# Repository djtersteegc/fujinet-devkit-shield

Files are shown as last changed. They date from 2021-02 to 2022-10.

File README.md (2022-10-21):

# fujinet-devkit-shield

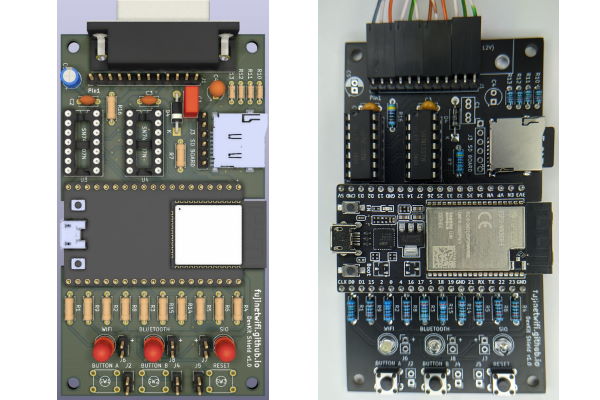
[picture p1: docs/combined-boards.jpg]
combined-boards


This is an alternative hardware platform for [FujiNet](https://fujinet.online/) that allows you to build your own using all through-hole technology (THT) components and an Espressif ESP32-DevKitC-VE devkit board.  You could probably also use a ESP32-DevKitC-VIE board, but you will need to either use an external IPEX connected antenna or engage in some micro soldering since the on-board PCB antenna is not connected by default. You must use ESP32-WROVER based devkit boards, the cheaper ESP32-WROOM boards lack the PSRAM needed by FujiNet code these days. 

The PCB is designed for flexibility in building, with different cabling options and headers for the buttons and LEDs if you want to mount this in your own enclosure. Most components are "jelly bean" parts you may already have or can be purchased for one or two cents in quantity from the usual China based suppliers.  Total cost of the build should be around $20, depending on where you source your parts.  Please see the assembly page for more details.

[Hardware Component Choices and Assembly](https://djtersteegc.github.io/fujinet-devkit-shield/assembly.html)

An interactive BOM and parts placement diagram is also available.

[Interactive Bill of Materials (BOM)](https://djtersteegc.github.io/fujinet-devkit-shield/ibom.html)

Currently this board is not supported by the FujiNet updater app so you will need to use Platform IO to build and upload your own binaries.  Build with the 8MB flash target since the devkit boards have half the flash of the 16MB WROVER modules used on the SIO mounted FujiNet designed by [mozzwald](https://github.com/mozzwald).  In normal operation is should not really matter since 6MB in the 16MB version is currently reserved for over the air (OTA) updates and the release build uses a little more than 2MB of flash as of March 2021 so lots of free space still for future development.

[Board bring up for FujiNet Platform.IO code](https://github.com/FujiNetWIFI/fujinet-platformio/wiki/Board-bring-up-for-FujiNet-Platform.IO-code)

STL's and the [DesignSpark Mechanical](https://www.rs-online.com/designspark/mechanical-software) source file for a 3D printable enclosure are in the **enclosure** directory. Assemble with four M3x10mm screws. Make sure to print 3 copies of the button file.

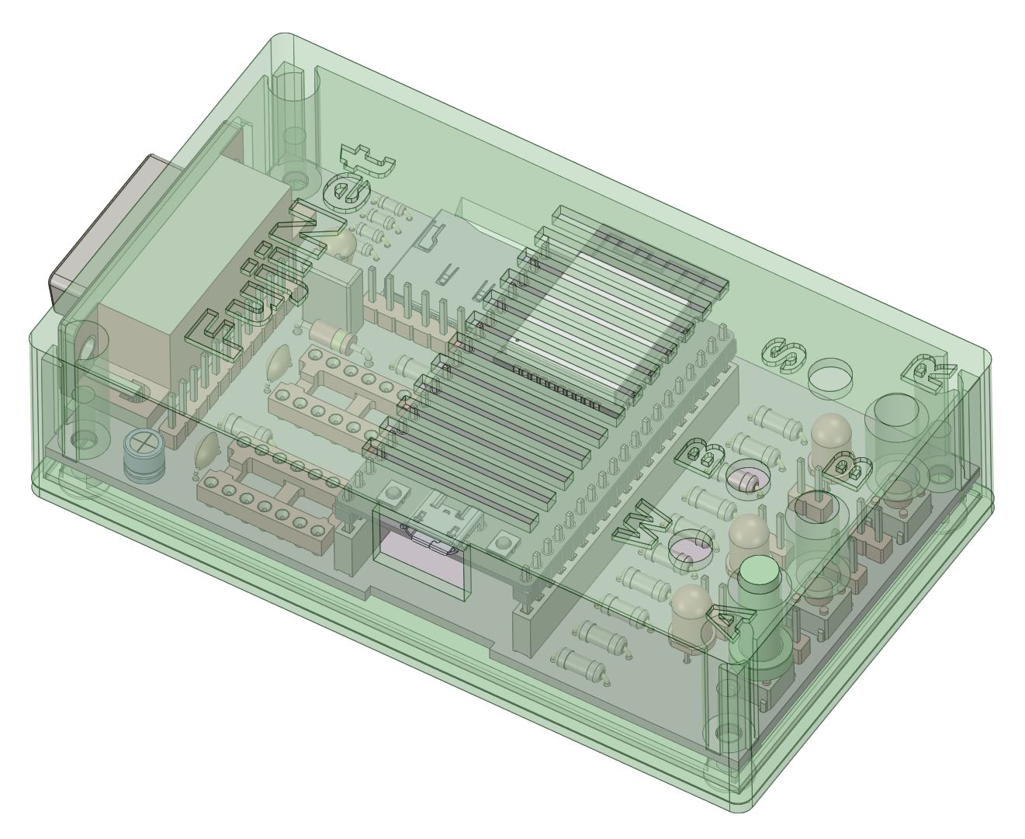
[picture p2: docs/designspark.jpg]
designspark


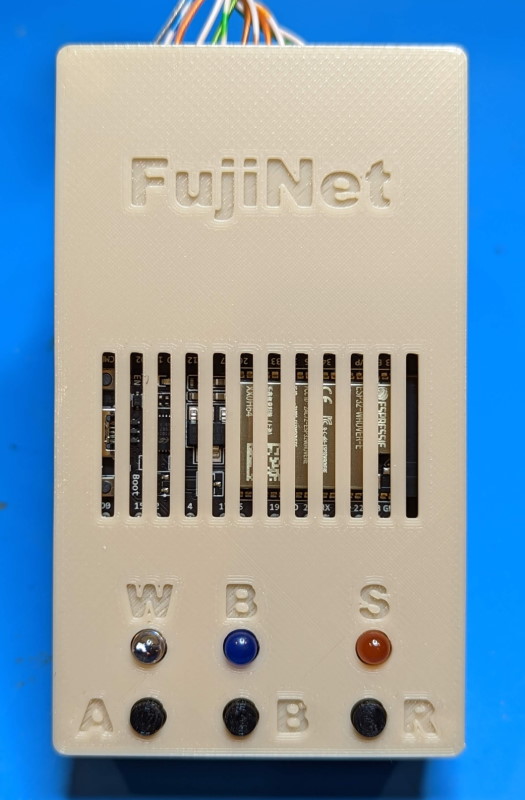
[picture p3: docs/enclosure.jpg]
enclosure


# Getting a Board

If I have extra PCB's, they will be listed on Tindie.

[https://www.tindie.com/products/tersteeg/fujinet-devkit-shield/](https://www.tindie.com/products/tersteeg/fujinet-devkit-shield/)

Otherwise you can download the Gerbers and use your favorite fab (JLCPCB, PCBWay, etc.) to make your own batch.  It's a standard two layer, 1oz copper board with dimensions of 99mm x 56mm so it squeaks under the 100mm x 100mm limit of the cheap Chinese fabs.

# Hardware Revisions

### Version 1.0

Mostly tested. Standard pin header cable with the SMD MicroSD card connector works.  Still waiting for DB15 connectors to test that cable configuration and a 4.7uf ceramic cap for audio in line. Will also build that one with the micro SD breakout board to verify.  External pin headers for the buttons and LEDs are also untested, but should work. Equivalent to version 1.3+ (pull-up resistors on the SIO and SD card lines) of the SIO port mounted FujiNet.

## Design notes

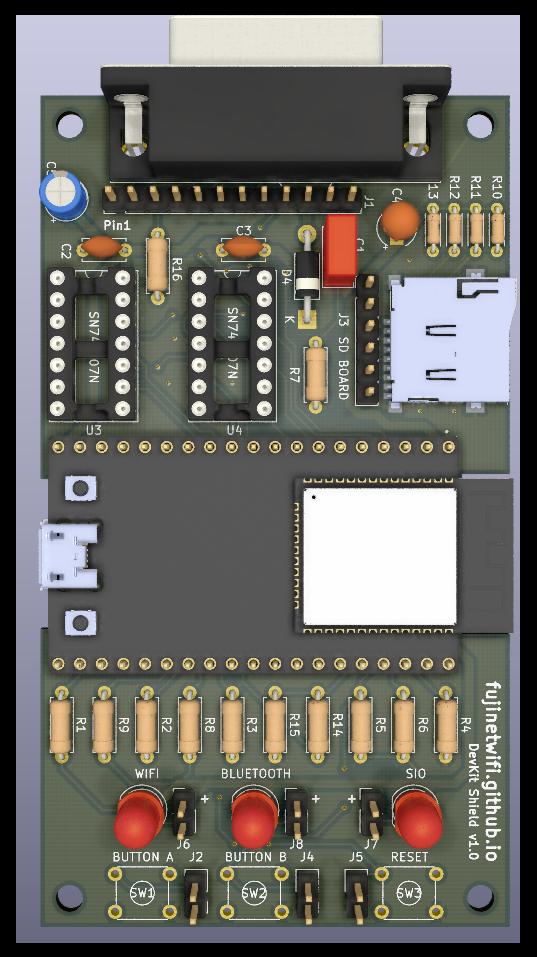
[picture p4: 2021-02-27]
docs/kicad-render.jpg

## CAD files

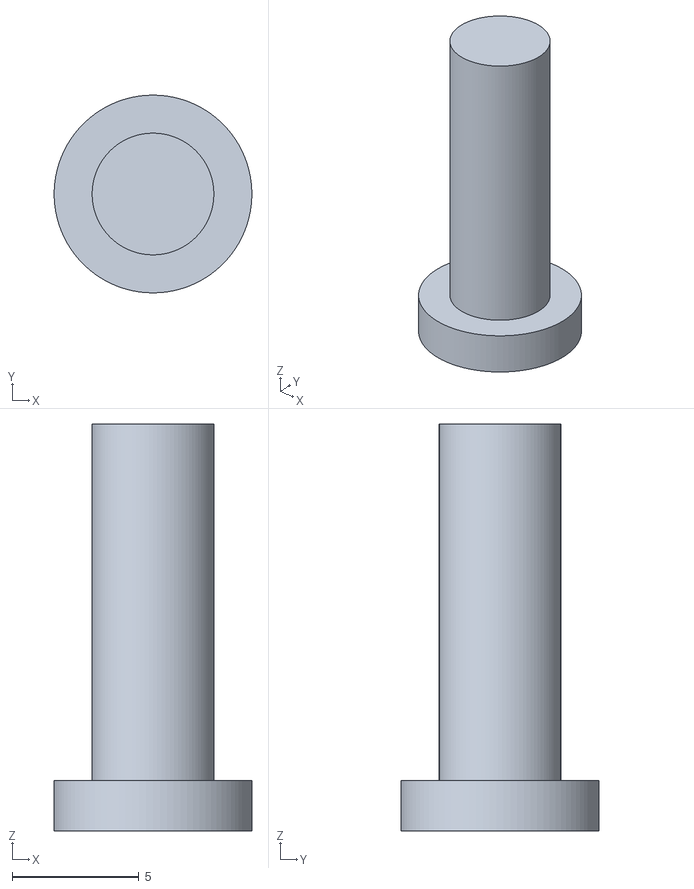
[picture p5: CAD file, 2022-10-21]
enclosure/fujinet button.stl
7.80 x 7.80 x 16.0

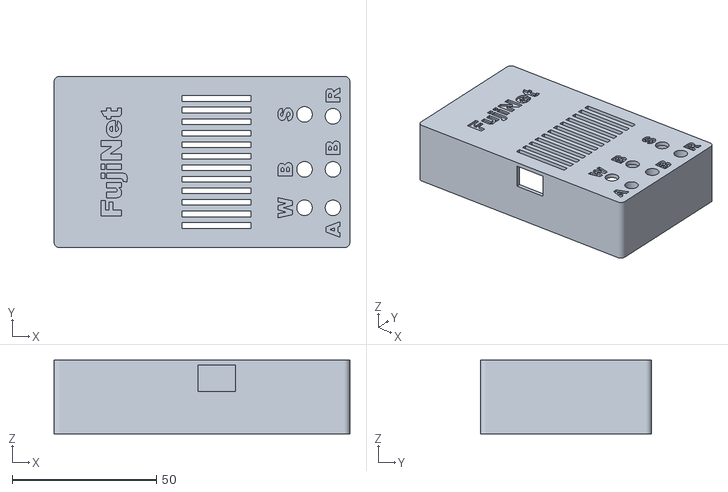
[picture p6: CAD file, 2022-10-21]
enclosure/fujinet body.stl
102.7 x 59.5 x 25.5

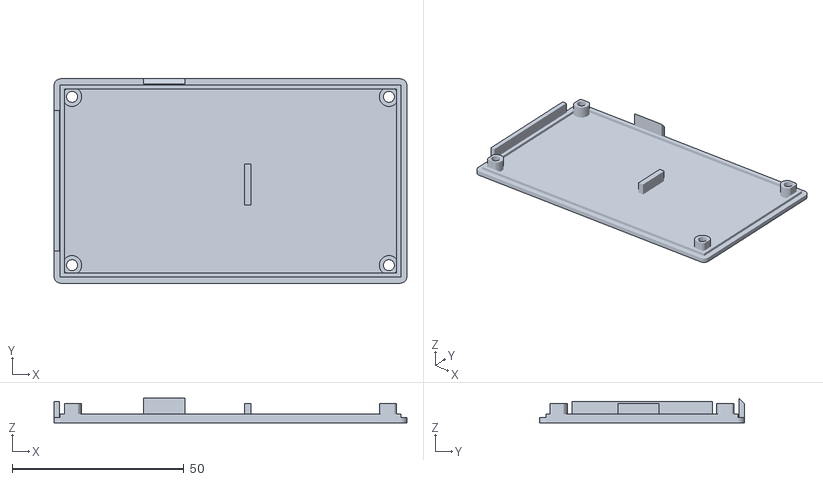
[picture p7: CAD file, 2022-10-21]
enclosure/fujinet lid.stl
102.7 x 59.5 x 7.20

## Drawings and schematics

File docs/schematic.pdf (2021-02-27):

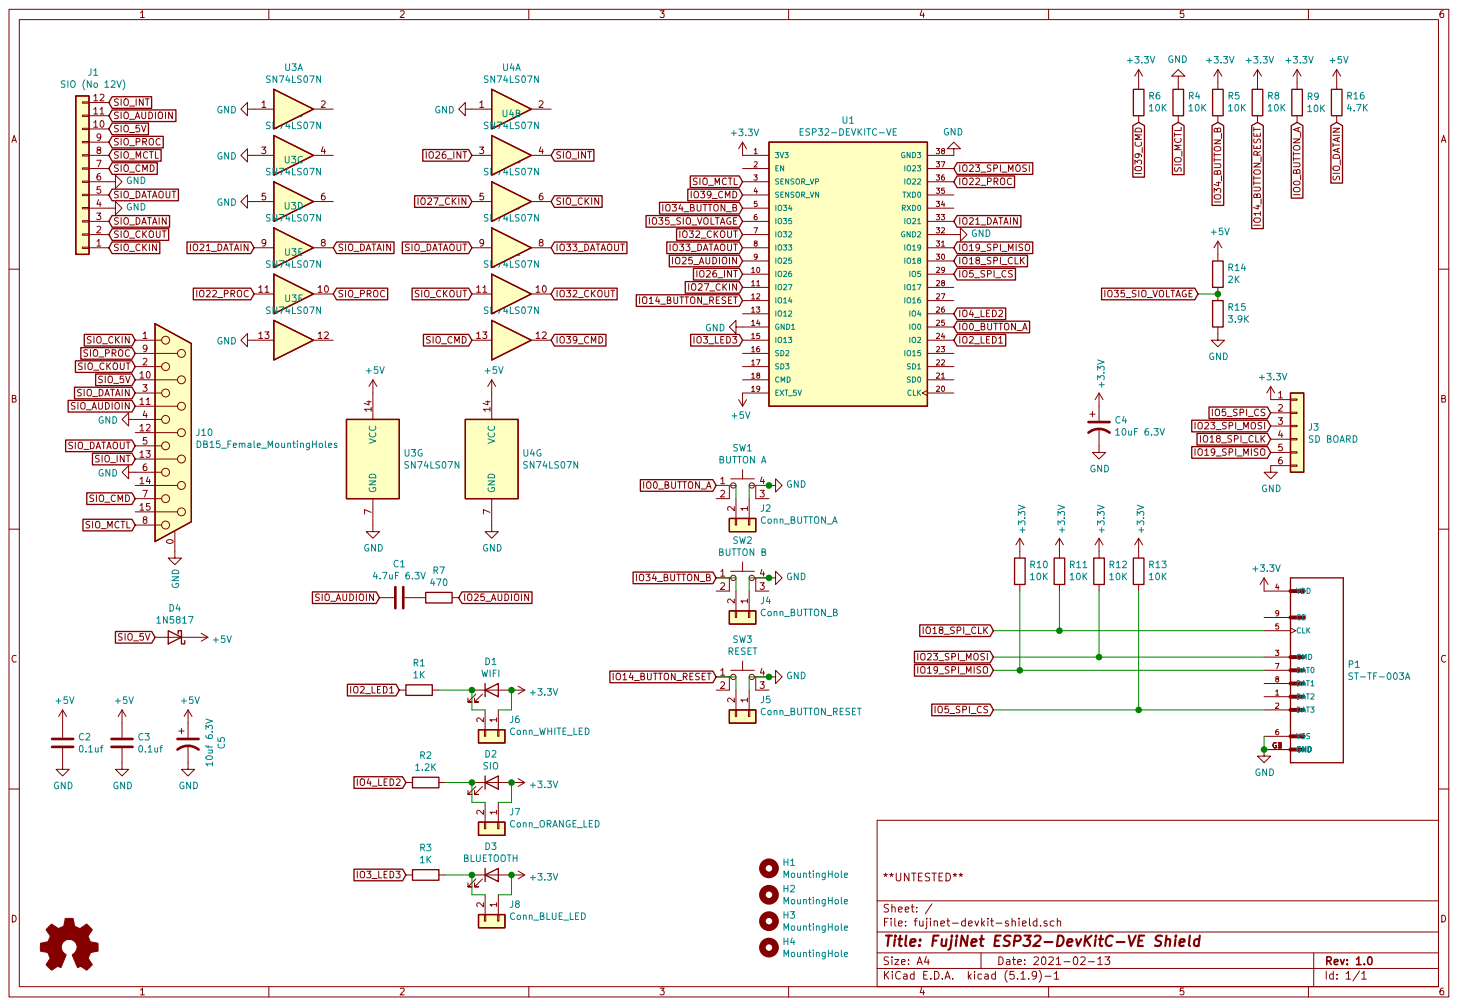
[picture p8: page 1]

File: fujinet-devkit-shield.sch Sheet: / **UNTESTED**

Id: 1/1 Title: FujiNet ESP32-DevKitC-VE Shield

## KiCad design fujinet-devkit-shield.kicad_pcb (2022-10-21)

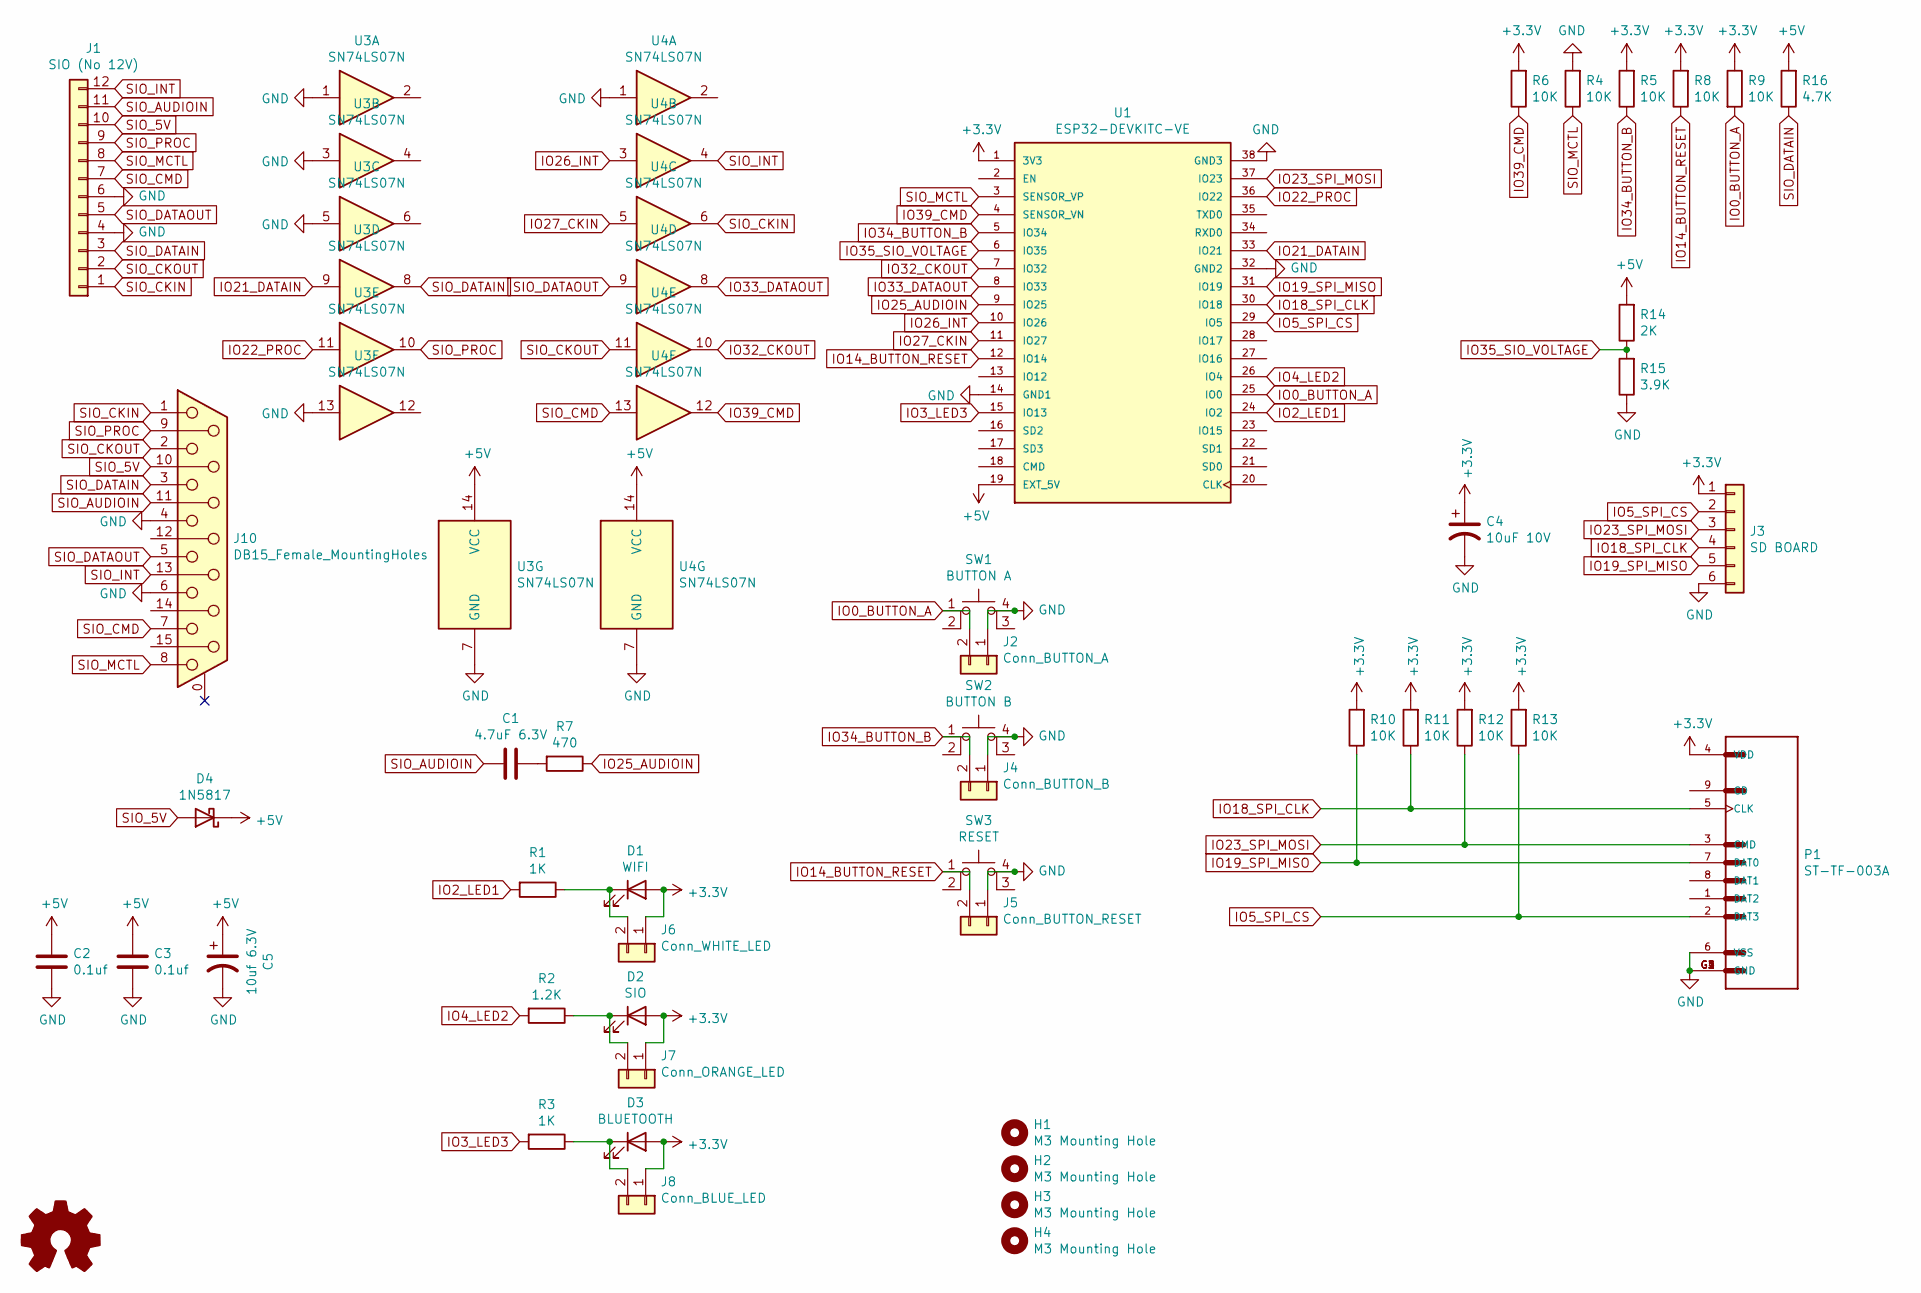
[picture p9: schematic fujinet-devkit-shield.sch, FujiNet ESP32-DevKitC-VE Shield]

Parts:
C1: 4.7uF 6.3V; C_Disc_D5.1mm_W3.2mm_P5.00mm
C2, C3: 0.1uf; C_Disc_D5.0mm_W2.5mm_P5.00mm
C4: 10uF 10V; CP_Radial_Tantal_D5.5mm_P5.00mm
C5: 10uf 6.3V; CP_Radial_D6.3mm_P2.50mm
D1: WIFI; LED_D5.0mm
D2: SIO; LED_D5.0mm
D3: BLUETOOTH; LED_D5.0mm
D4: 1N5817; D_DO-41_SOD81_P10.16mm_Horizontal
H1, H2, H3, H4: M3 Mounting Hole; MountingHole_3.2mm_M3
J1: SIO (No 12V); PinHeader_1x12_P2.54mm_Vertical
J2: Conn_BUTTON_A; PinHeader_1x02_P2.54mm_Vertical
J3: SD BOARD; PinHeader_1x06_P2.54mm_Vertical
J4: Conn_BUTTON_B; PinHeader_1x02_P2.54mm_Vertical
J5: Conn_BUTTON_RESET; PinHeader_1x02_P2.54mm_Vertical
J6: Conn_WHITE_LED; PinHeader_1x02_P2.54mm_Vertical
J7: Conn_ORANGE_LED; PinHeader_1x02_P2.54mm_Vertical
J8: Conn_BLUE_LED; PinHeader_1x02_P2.54mm_Vertical
J10: DB15_Female_MountingHoles; DSUB-15_Female_Horizontal_P2.77x2.84mm_EdgePinOffset4.94mm_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
P1: ST-TF-003A; SUNTECH_ST-TF-003A
R1, R3: 1K; R_Axial_DIN0207_L6.3mm_D2.5mm_P7.62mm_Horizontal
R2: 1.2K; R_Axial_DIN0207_L6.3mm_D2.5mm_P7.62mm_Horizontal
R4, R5, R6, R8, R9, R10, R11, R12, R13: 10K; R_Axial_DIN0207_L6.3mm_D2.5mm_P7.62mm_Horizontal
R7: 470; R_Axial_DIN0207_L6.3mm_D2.5mm_P7.62mm_Horizontal
R14: 2K; R_Axial_DIN0207_L6.3mm_D2.5mm_P7.62mm_Horizontal
R15: 3.9K; R_Axial_DIN0207_L6.3mm_D2.5mm_P7.62mm_Horizontal
R16: 4.7K; R_Axial_DIN0207_L6.3mm_D2.5mm_P7.62mm_Horizontal
SW1: BUTTON A; SW_TH_Tactile_Omron_B3F-10xx
SW2: BUTTON B; SW_TH_Tactile_Omron_B3F-10xx
SW3: RESET; SW_TH_Tactile_Omron_B3F-10xx
U1: ESP32-DEVKITC-VE; MODULE_ESP32-DEVKITC-32U; PARTREV N/A
U3, U4: SN74LS07N; DIP-14_W7.62mm_Socket_LongPads

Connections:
+3V3: C4.1, D1.2 (A), D2.2 (A), D3.2 (A), J3.1, J6.1, J7.1, J8.1, P1.4 (VDD), R5.2, R6.2, R8.2, R9.1, R10.2, R11.2, R12.2, R13.2, U1.1 (3V3)
+5V: C2.1, C3.1, C5.1, D4.1 (K), R14.2, R16.2, U1.19 (EXT_5V), U3.14 (VCC), U4.14 (VCC)
GND: C2.2, C3.2, C4.2, C5.2, J1.4, J1.6, J2.1, J3.6, J4.1, J5.1, J10.4, J10.6, P1.6 (VSS), P1.G1 (GND), P1.G2 (GND), P1.G3 (GND), P1.G4 (GND), R4.2, R15.1, SW1.4 (A), SW2.4 (A), SW3.4 (A), U1.14 (GND1), U1.32 (GND2), U1.38 (GND3), U3.1, U3.3, U3.5, U3.7 (GND), U3.13, U4.1, U4.7 (GND)
IO0_BUTTON_A: J2.2, R9.2, SW1.1, U1.25 (IO0)
IO2_LED1: R1.2, U1.24 (IO2)
IO3_LED3: R3.2, U1.15 (IO13)
IO4_LED2: R2.2, U1.26 (IO4)
IO5_SPI_CS: J3.2, P1.2 (DAT3), R13.1, U1.29 (IO5)
IO14_BUTTON_RESET: J5.2, R8.1, SW3.1, U1.12 (IO14)
IO18_SPI_CLK: J3.4, P1.5 (CLK), R11.1, U1.30 (IO18)
IO19_SPI_MISO: J3.5, P1.7 (DAT0), R10.1, U1.31 (IO19)
IO21_DATAIN: U1.33 (IO21), U3.9
IO22_PROC: U1.36 (IO22), U3.11
IO23_SPI_MOSI: J3.3, P1.3 (CMD), R12.1, U1.37 (IO23)
IO25_AUDIOIN: R7.1, U1.9 (IO25)
IO26_INT: U1.10 (IO26), U4.3
IO27_CKIN: U1.11 (IO27), U4.5
IO32_CKOUT: U1.7 (IO32), U4.10
IO33_DATAOUT: U1.8 (IO33), U4.8
IO34_BUTTON_B: J4.2, R5.1, SW2.1, U1.5 (IO34)
IO35_SIO_VOLTAGE: R14.1, R15.2, U1.6 (IO35)
IO39_CMD: R6.1, U1.4 (SENSOR_VN), U4.12
unnamed: C1.2, R7.2
unnamed: D1.1 (K), J6.2, R1.1
unnamed: D2.1 (K), J7.2, R2.1
unnamed: D3.1 (K), J8.2, R3.1
SIO_5V: D4.2 (A), J1.10, J10.10
SIO_AUDIOIN: C1.1, J1.11, J10.11 (P111)
SIO_CKIN: J1.1, J10.1, U4.6
SIO_CKOUT: J1.2, J10.2, U4.11
SIO_CMD: J1.7, J10.7, U4.13
SIO_DATAIN: J1.3, J10.3, R16.1, U3.8
SIO_DATAOUT: J1.5, J10.5, U4.9
SIO_INT: J1.12, J10.13, U4.4
SIO_MCTL: J1.8, J10.8, R4.1, U1.3 (SENSOR_VP)
SIO_PROC: J1.9, J10.9, U3.10

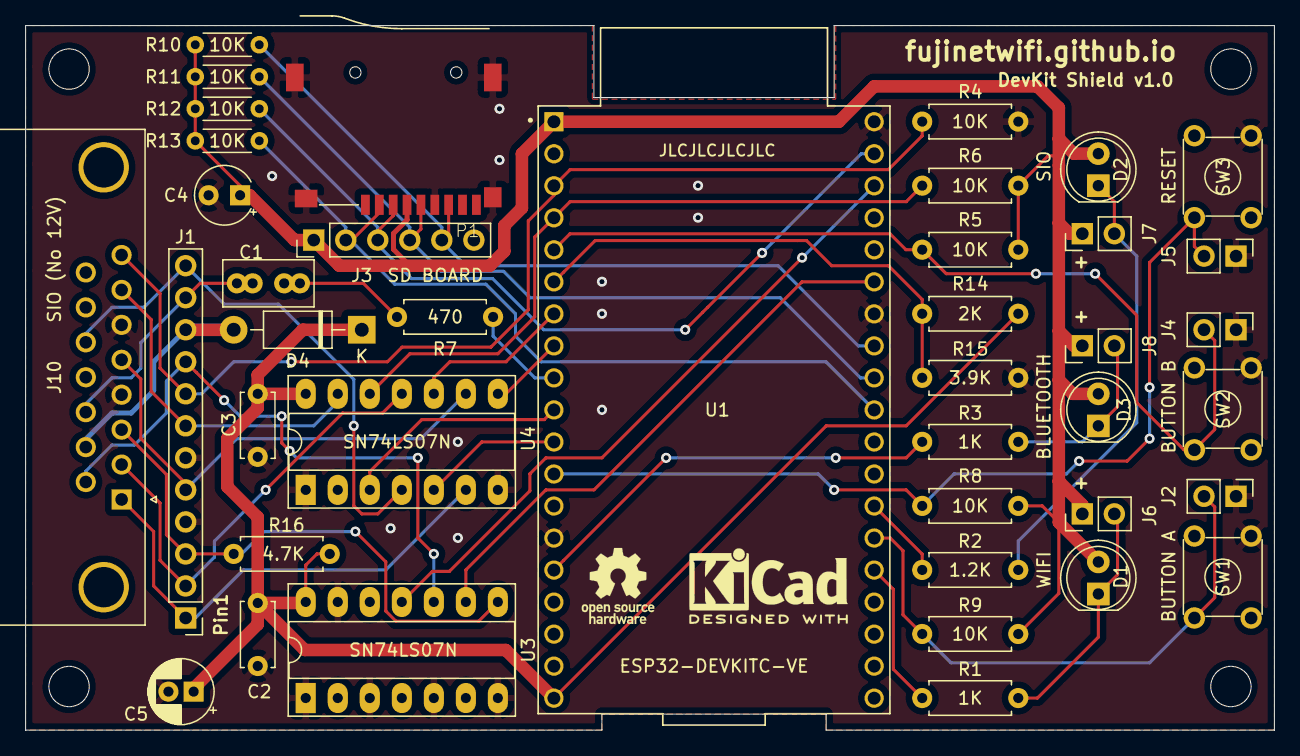
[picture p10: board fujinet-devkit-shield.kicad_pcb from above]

Board: 2 copper layers, 99.1 x 55.9 mm, 45 parts (0 on the bottom side), 36 nets.

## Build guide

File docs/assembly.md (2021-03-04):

# Hardware Component Choices and Assembly

[Interactive Bill of Materials (BOM)](ibom.html)

### Devkit Board

Espressif ESP32-DevKitC-VE is the recommended choice. They are pretty much $11 everywhere, so I just used [Amazon](https://www.amazon.com/gp/product/B087TNPQCV).  I like to mount mine on [female headers](https://www.aliexpress.com/item/32724478308.html) so they can be easily removed and/or reused in other projects.

### Micro SD Card Connector

This can be either the commonly available push-push [connector](https://www.aliexpress.com/item/4001278357176.html) with locating pins from Aliexpress, eBay, LCSC, etc.

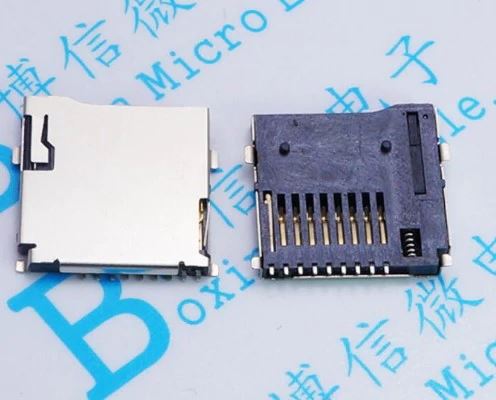
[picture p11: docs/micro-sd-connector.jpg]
micro-sd-connector


Or a push-pull [break out board](https://www.aliexpress.com/item/32886674838.html) mounted via the J3 header pins from the same Chinese suppliers.

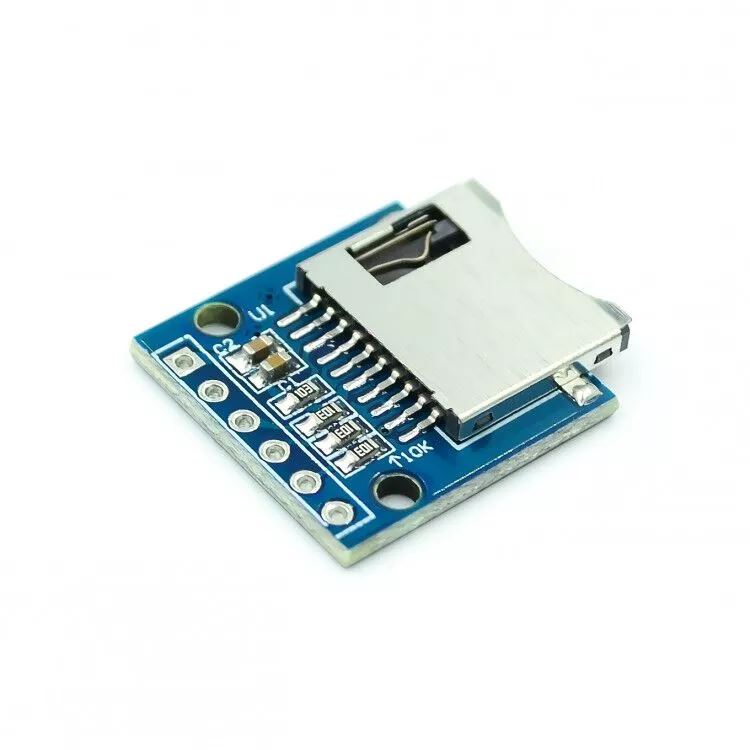
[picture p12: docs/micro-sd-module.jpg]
micro-sd-module
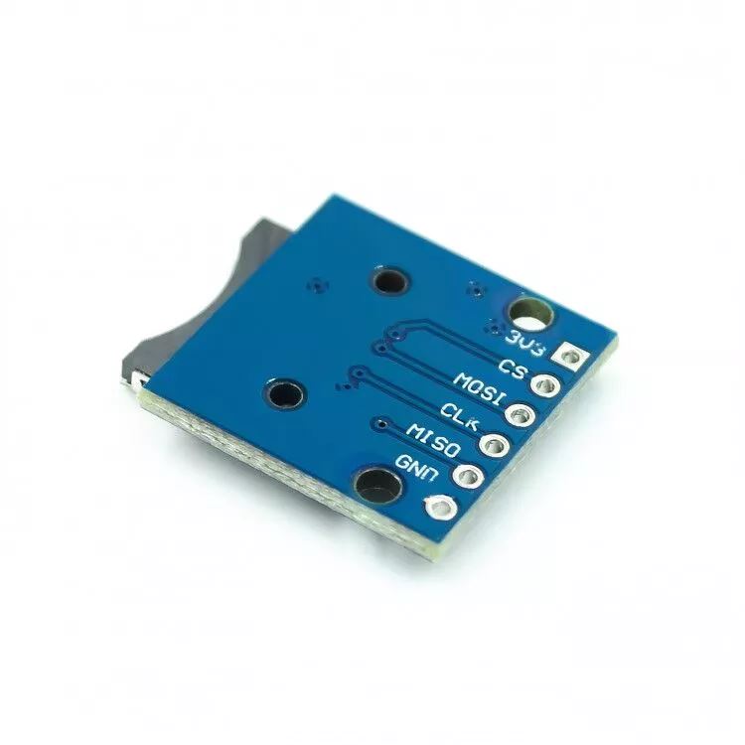
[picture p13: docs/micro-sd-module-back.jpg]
micro-sd-module-back


Yes, the first option is SMD and not THT, but it's pretty easy to solder and gives a cleaner build IMHO so I added it as an option.  When using the SMD connector you also need to populate the pull-up resistors R10 thru R13.  The break out board already has these mounted.

### Cable Connector

You can use either J1 to mount any standard 12 position (12p) 2.54mm type header connector or use J10 to mount a female DB15 connector. If you want something keyed to prevent reverse insertion I would recommend right angle [XH2.54 style connectors](https://www.aliexpress.com/item/32823261625.html).

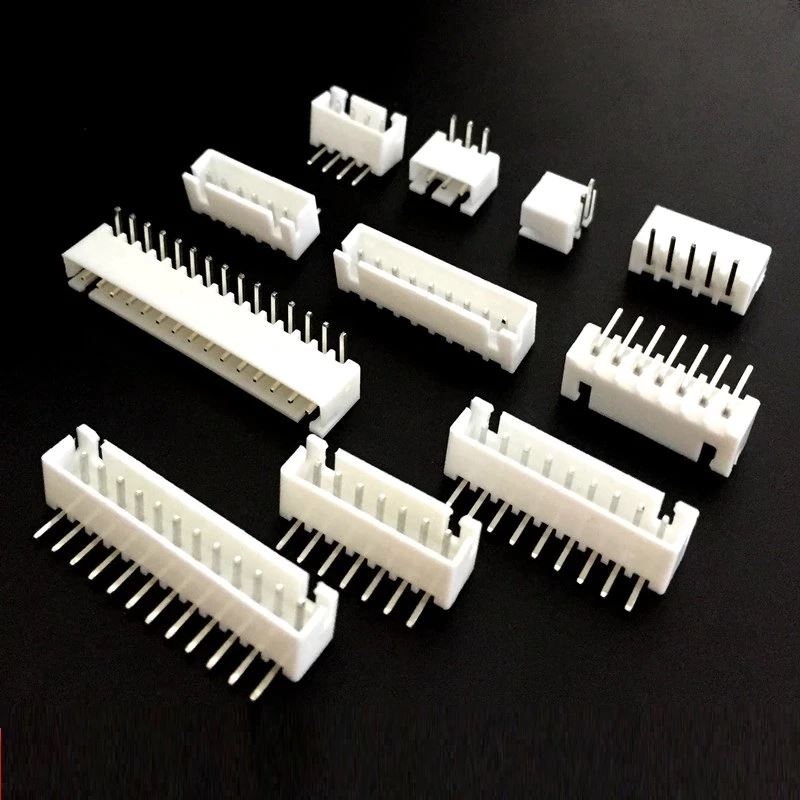
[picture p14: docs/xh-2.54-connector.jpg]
xh-2.54-connector


You can also buy prewired 12p [XH2.54 cables](https://www.aliexpress.com/item/1005001463221962.html) if you don't want to crimp your own.

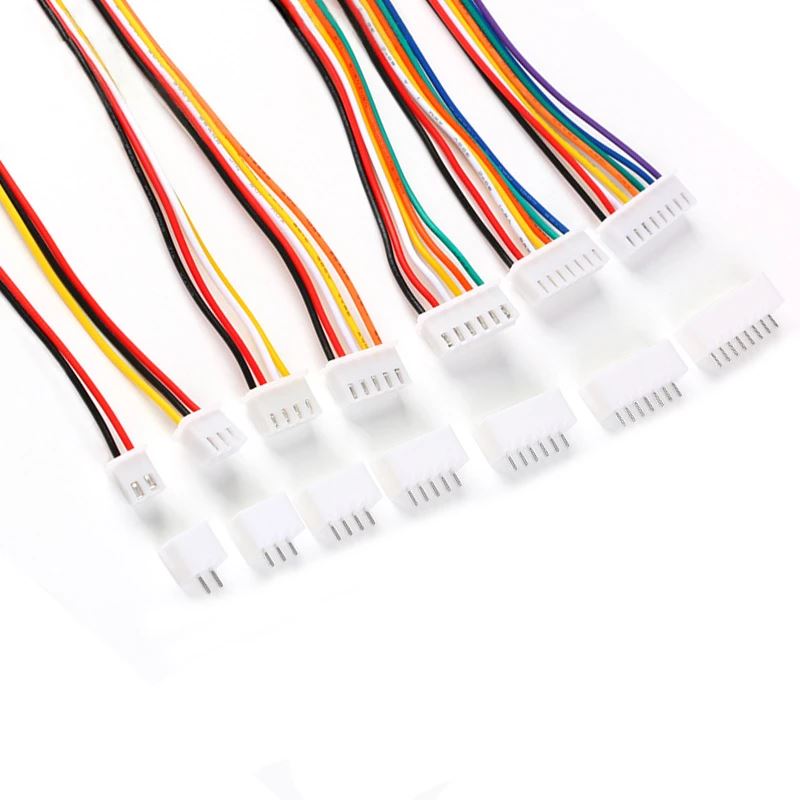
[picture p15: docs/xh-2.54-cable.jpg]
xh-2.54-cable


When wiring J1 skip pin 12 (the +12V line on old 400/800's) from the SIO connector and wire SIO pin 13 to pin 12 on J1.  When using J10 wire pin for pin, but pin 12 is not connected on the PCB so you don't really need to wire it.

For the SIO plug on the Atari side, I've had great luck using this 3D printed model, [https://www.thingiverse.com/thing:2883606/files](https://www.thingiverse.com/thing:2883606/files), and KK 396 style crimp connectors.

### Bulk Capacitors

C4 and C5 are bulk storage capacitors for the 3.3V (SD card) and 5V lines.  They are optional since the devkit board already has caps on-board, but if you have a marginal SIO 5V line or experience other power issues, they could help stabilize the overall board.  Any value between 10uf to 47uf is fine.

### Resistors

Either 1/4W or 1/8W can be used in all locations except the pull-ups on the SD card.

R1, R2, and R3 control the LED brightness. The values listed are the same as the SIO mounted Fujinet, but you may want to pick other values if using different LED's with different [Vf](https://electronics.stackexchange.com/questions/173468/easy-way-to-figure-out-a-leds-vf-in-order-to-pick-an-appropriate-resistor) values or prefer brighter or dimmer LEDs.  I generally shoot for around 1ma to 2ma of current on a standard 20ma LED depending on color.  Remember, these are being driven by 3.3V, not the normal 5V you may see on an AVR Arduino project.  A good calculator is at:

[http://ledcalc.com/](http://ledcalc.com/)

R14 and R15 are optional.  They form a voltage divider than is only used these days to show SIO voltage in the FujiNet web interface.

### Diode D4

This is to prevent back feeding of the SIO 5V line if you also plug the devkit board into USB while connected to your Atari. If you are 100% certain you will never do this, you can simply bridge this connection.  Or leave it off completely and only power your FujiNet via USB.  A 1N5817 is the recommended value here, but others like a 1N5819 will also work, just with a slightly higher voltage drop.

### External Headers

If you plan on mounting your FujiNet in a larger enclosure, you can use J2, J4, J5, J6, J7, and J8 instead of the PCB mounted buttons and LEDs.

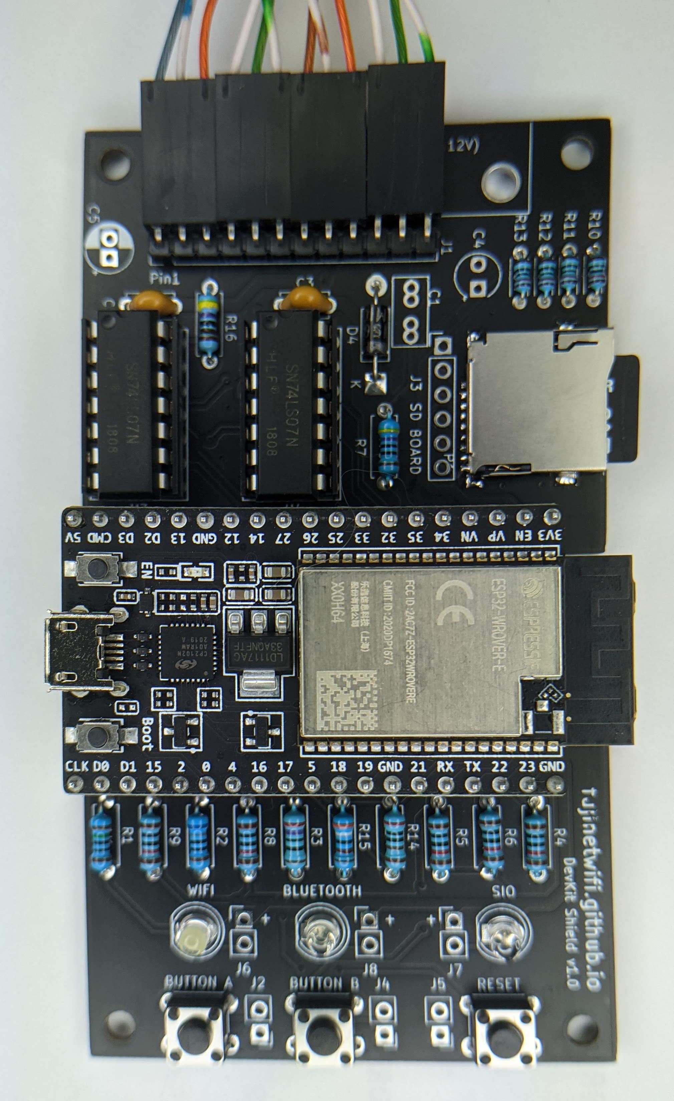
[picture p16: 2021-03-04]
docs/assembled-board.jpg

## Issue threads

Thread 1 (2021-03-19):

Picture showing pin numbering on devkit board is illegible

e474, 2021-03-19:
Hi,

   The picture showing the pin labels on the devkit board (combined-boards.jpg) is illegible at 600x800. I know the pins are listed in the PDF, but for buying a board online, being able to compare the pins on 2 pictures makes things a lot easier.

    Thanks for developing this though, it's really good!

Verault, 2025-02-07:
If the owner cant be bothered to address the one and only issue ever posted nor make any changes in years I think its safe to say this repository is dead and best not attempted.

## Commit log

2021-02-11 Add exported schematic and board render
2021-02-27 Files sent to JCL
    [fujinet-devkit-shield-B_Cu.gbr, fujinet-devkit-shield-B_Mask.gbr, fujinet-devkit-shield-B_Paste.gbr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]
2021-02-27 Remove old board image
2021-03-04 First pass at some docs
    [fujinet-devkit-shield.kicad_pcb, fujinet-devkit-shield.sch]
2022-10-21 Fixup 3D models
    [fujinet-devkit-shield.kicad_pcb]
2022-10-21 Add enclosure files
    [fujinet body.stl, fujinet button.stl, fujinet lid.stl]
